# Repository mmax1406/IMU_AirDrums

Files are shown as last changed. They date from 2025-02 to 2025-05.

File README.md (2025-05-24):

# IMU_AirDrums

## Introduction
Using two BNO055 IMUs and an Arduino Uno to create air drums.
Each IMU provides absolute orientation data, which is sent to a Python script for processing.
After an initial calibration step, the 3D space is divided into five distinct zones: three lower (downward) strike zones and two upper strike zones.
When a movement is detected within one of these zones, it is interpreted as a drum hit.

## Setup
Each drum stick has a BN055 IMU 
<p float="left">
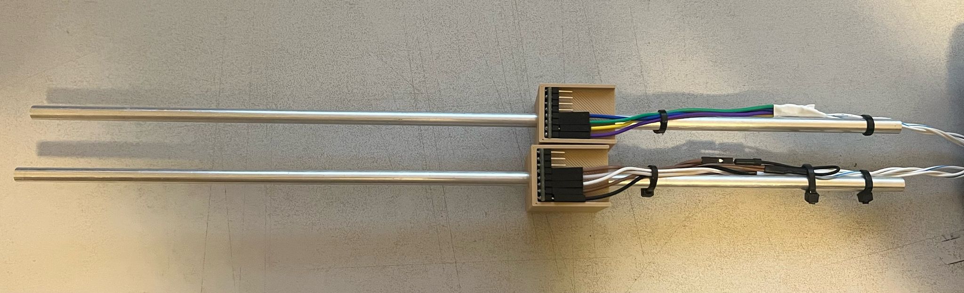
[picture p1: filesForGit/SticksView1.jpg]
  
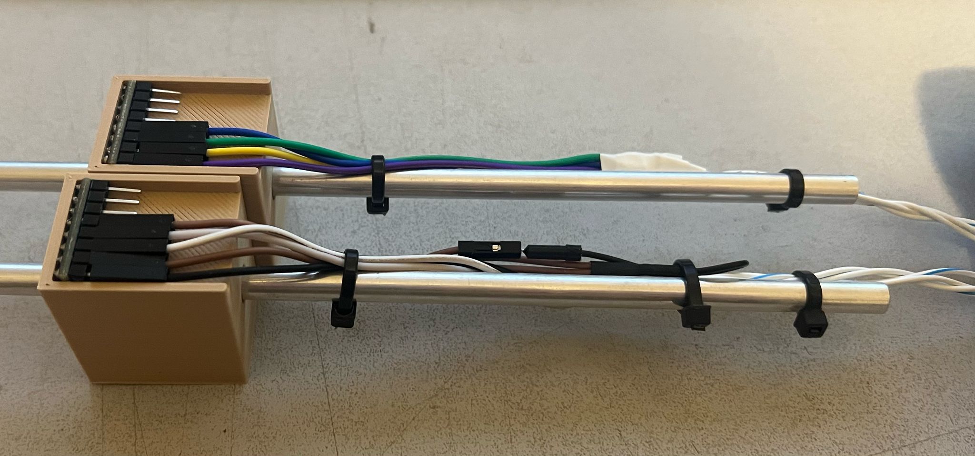
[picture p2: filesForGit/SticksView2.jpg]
   
</p>
note that the IMU allows 2 addresses 0x28 and 0x29 by shortning a pin so thats how they can sit on the same protocol.

And this is the Uno: 
<p float="left">
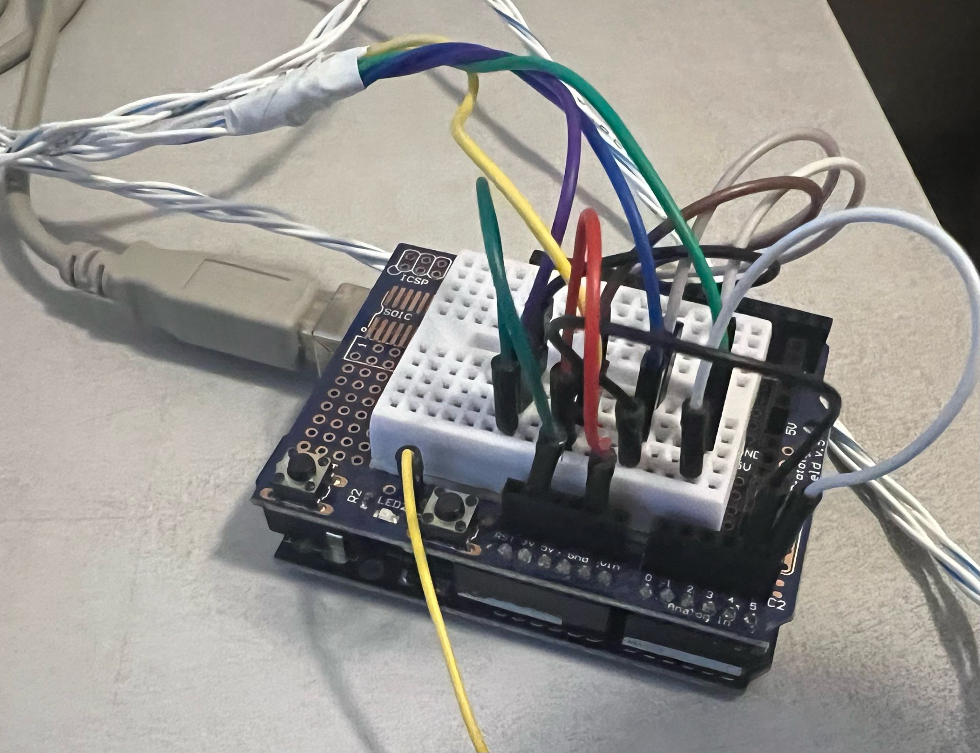
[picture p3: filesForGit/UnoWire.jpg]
  
</p>
Does it help? probably not ... but theres nothing special I2C on both sensors and electricty to them.

Finally on the PC side i wanted real drums so ive used an emulator called cakewalk with a drums plugin.
To connect to cakewalk ive used loopMIDI and sent the MIDI signal via python (this is the delay i can play with). 
<p float="left">
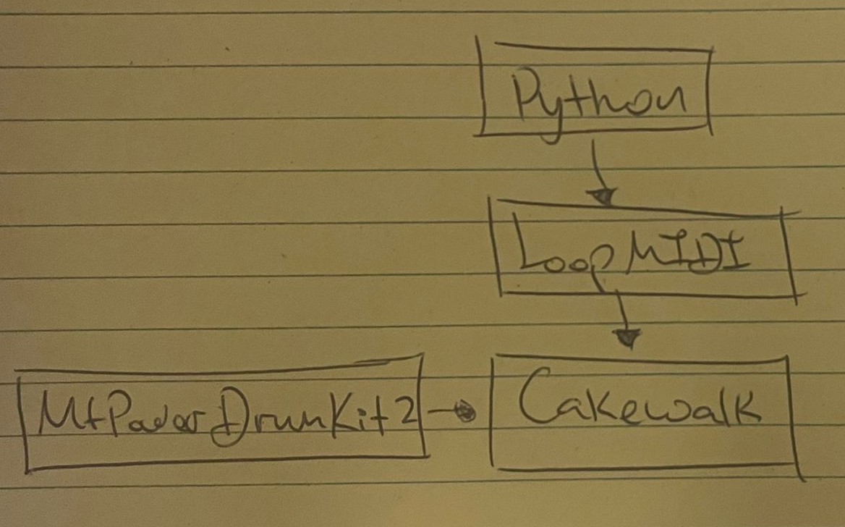
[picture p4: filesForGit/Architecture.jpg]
  
</p>

## To Do
- Hit Volume control using the accleration value.
- Work more on the delay reduction.

## Demonstration video
A small video of the system working

https://github.com/user-attachments/assets/ffe69c20-fb8f-49c2-923d-1a3709275ff4

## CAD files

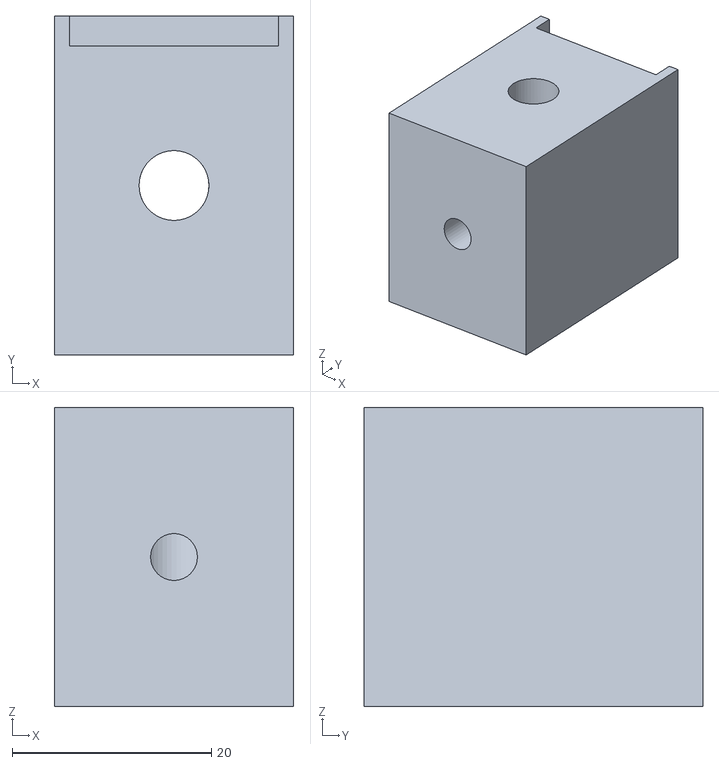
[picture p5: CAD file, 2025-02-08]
CAD/drumHandles v7.stl
24.0 x 34.0 x 30.0

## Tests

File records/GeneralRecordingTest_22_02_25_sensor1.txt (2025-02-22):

0,0.5224,0.4592,-0.5531,0.4586,3.0,-0.499215506284969,-0.2594394763192156,-1.659806445272789,-0.0023217320693640353,1740234139.310265
0,0.5224,0.4592,-0.5531,0.4586,3.0,-0.499215506284969,-0.2594394763192156,-1.6642553573984564,0.004448912125667448,1740234139.3344746
0,0.5224,0.4592,-0.5531,0.4586,3.0,-0.499215506284969,-0.2594394763192156,-1.6642553573984564,0.0,1740234139.3588767
0,0.5225,0.4592,-0.553,0.4586,3.0,-0.4995609359708624,-0.24676949321326447,-1.6515853742924962,-0.012669983105960236,1740234139.387862
0,0.5225,0.4592,-0.5531,0.4586,3.0,-0.5046526232843576,-0.2592316775084669,-1.676717541693674,0.02513216740117774,1740234139.4075923
0,0.5226,0.4591,-0.5532,0.4584,3.0,-0.533701835068257,-0.2615066053240014,-1.6665302852139872,-0.010187256479686768,1740234139.4366567
0,0.5228,0.4588,-0.5534,0.4581,3.0,-0.5917431239445818,-0.2555477528758274,-1.6582965049502956,-0.008233780263691592,1740234139.4583752
0,0.523,0.4586,-0.5536,0.4579,3.0,-0.6374510584867608,-0.2597687647429723,-1.6684763692656075,0.010179864315311926,1740234139.486153
0,0.5235,0.4583,-0.5537,0.4575,3.0,-0.7128977820971727,-0.24094031165444108,-1.6454269043099252,-0.023049464955682275,1740234139.5072882
0,0.5239,0.4581,-0.5538,0.4572,3.0,-0.7705657453064418,-0.23248306461948687,-1.6557981103635173,0.010371206053592097,1740234139.5351746
0,0.5239,0.4583,-0.5538,0.457,3.0,-0.7707013379435921,-0.2534949847946564,-1.6852672775736275,0.02946916721011017,1740234139.5597103
0,0.524,0.4584,-0.5536,0.4568,3.0,-0.7722356570513398,-0.23902117661725697,-1.649781549221064,-0.035485728352563584,1740234139.5846465
0,0.5242,0.4591,-0.5533,0.4563,3.0,-0.7559286220816546,-0.2744641329827857,-1.6996983137639876,0.04991676454292371,1740234139.6086006
0,0.524,0.4597,-0.5533,0.4561,3.0,-0.7207624732871238,-0.3373498162771398,-1.7271410406928194,0.027442726928831762,1740234139.6366847
0,0.5232,0.4609,-0.5532,0.4559,3.0,-0.6113215780771384,-0.45138435412221156,-1.778289895243525,0.051148854550705725,1740234139.6579187
0,0.5226,0.4617,-0.553,0.4561,3.0,-0.5072416529193333,-0.5104866750964732,-1.7233576783727096,-0.05493221687081551,1740234139.6879406
0,0.5212,0.4626,-0.5527,0.457,3.0,-0.30489913617370235,-0.5681595295005764,-1.7219282118025583,-0.0014294665701513054,1740234139.7068443
0,0.5197,0.4643,-0.5522,0.4576,3.0,-0.05672650505499632,-0.685489678650697,-1.7815855065485722,0.05965729474601389,1740234139.7369335
0,0.5175,0.4685,-0.5505,0.4579,3.0,0.42400975010556863,-0.9197436026850312,-1.8985092814327902,0.11692377488421801,1740234139.7600203
0,0.5162,0.471,-0.5494,0.458,3.0,0.7089370327789197,-1.0507065830338433,-1.7952183377472766,-0.10329094368551361,1740234139.7851458
0,0.5151,0.4725,-0.5481,0.4592,3.0,1.0012391636343807,-1.0495160161583783,-1.663064790522994,-0.13215354722428252,1740234139.8094158
0,0.515,0.4725,-0.5472,0.4604,3.0,1.1276243922799551,-0.9363763825241449,-1.5511157237642386,-0.11194906675875549,1740234139.83476
0,0.5148,0.4735,-0.5458,0.4614,3.0,1.3330308274845493,-0.8690072643486246,-1.5968862392229313,0.04577051545869271,1740234139.859683
0,0.5148,0.475,-0.5444,0.4614,3.0,1.4956394783668543,-0.8574049024610133,-1.6526529955108504,0.05576675628791916,1740234139.8875551
0,0.5141,0.4777,-0.5421,0.4622,3.0,1.8649696051639069,-0.8655749014226615,-1.6724253563600953,0.01977236084924483,1740234139.9084153
0,0.5125,0.4794,-0.5406,0.4639,3.0,2.2381942208633063,-0.8660936079718908,-1.6647740639476973,-0.007651292412397925,1740234139.936355
0,0.5093,0.4821,-0.538,0.4677,3.0,2.9466207696674473,-0.8420358671503152,-1.6401976165768724,-0.024576447370824983,1740234139.960444
0,0.5059,0.4832,-0.5357,0.4728,3.0,3.634703000009324,-0.6807353036776931,-1.5029547939258476,-0.13724282265102472,1740234139.9853165
0,0.4949,0.4847,-0.5342,0.4846,3.0,5.1375310599964905,-0.6628585268201732,-1.6463785805409485,0.1434237866151009,1740234140.010263
0,0.4868,0.4897,-0.5317,0.4903,3.0,6.371908646569352,-0.9165109226741492,-1.9179077532524293,0.2715291727114808,1740234140.0381656
0,0.4758,0.5004,-0.5271,0.4954,3.0,8.188974999935851,-1.572768394800704,-2.3205128295250175,0.4026050762725881,1740234140.0605896
0,0.4736,0.5043,-0.5275,0.4931,3.0,8.388872435348901,-2.0711036130591367,-2.1625905756568966,-0.15792225386812087,1740234140.0875502
0,0.4794,0.5134,-0.529,0.4763,3.0,7.478108755768744,-3.31707087585977,-2.910222620199093,0.7476320445421965,1740234140.1119683
0,0.4812,0.5167,-0.5315,0.4679,3.0,6.909572378509722,-4.014291974105191,-2.361476455643877,-0.5487461645552161,1740234140.1380346
0,0.4796,0.5173,-0.5344,0.4656,3.0,6.741255096479051,-4.44169858462314,-2.091661967916399,-0.2698144877274782,1740234140.1626542
0,0.4761,0.5131,-0.5374,0.4703,3.0,6.845099477211704,-4.313913518774569,-1.5364702915499002,-0.5551916763664986,1740234140.1873271
0,0.4726,0.5006,-0.541,0.483,3.0,6.923701430782472,-3.3020647798936125,-0.6524066185175048,-0.8840636730323954,1740234140.2105656
0,0.4681,0.4833,-0.5461,0.4991,3.0,6.866043682713752,-1.9826006592917622,-0.3447912367966217,-0.3076153817208831,1740234140.2360384
0,0.4657,0.4641,-0.5491,0.516,3.0,6.659024329712963,-0.2726030331818663,0.04574226871144749,-0.3905335055080692,1740234140.2599359
0,0.4854,0.4581,-0.5306,0.5225,3.0,6.43549880305045,2.650700635567887,1.2590483113512803,-1.2133060426398328,1740234140.288032
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

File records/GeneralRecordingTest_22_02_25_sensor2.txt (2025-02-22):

0,0.5986,0.3401,-0.636,0.3486,3.0,-0.536418361511835,0.06417728716959914,-1.659806445272789,-0.0023217320693640353,1740234139.310265
0,0.5986,0.34,-0.636,0.3485,3.0,-0.5505724291468539,0.07164669352081887,-1.6642553573984564,0.004448912125667448,1740234139.3344746
0,0.5986,0.34,-0.636,0.3486,3.0,-0.5434243245573498,0.07181386055944472,-1.6642553573984564,0.0,1740234139.3588767
0,0.5986,0.34,-0.636,0.3486,3.0,-0.5434243245573498,0.07181386055944472,-1.6515853742924962,-0.012669983105960236,1740234139.387862
0,0.5986,0.34,-0.636,0.3486,3.0,-0.5434243245573498,0.07181386055944472,-1.676717541693674,0.02513216740117774,1740234139.4075923
0,0.5986,0.34,-0.636,0.3486,3.0,-0.5434243245573498,0.07181386055944472,-1.6665302852139872,-0.010187256479686768,1740234139.4366567
0,0.5987,0.3398,-0.6361,0.3485,3.0,-0.5724923428326747,0.07291631738286242,-1.6582965049502956,-0.008233780263691592,1740234139.4583752
0,0.5988,0.3397,-0.6362,0.3484,3.0,-0.594551077794506,0.06638046631670136,-1.6684763692656075,0.010179864315311926,1740234139.486153
0,0.5989,0.3396,-0.6361,0.3483,3.0,-0.6091248279409172,0.08841482997519279,-1.6454269043099252,-0.023049464955682275,1740234139.5072882
0,0.5991,0.3395,-0.636,0.3482,3.0,-0.6278540534810304,0.11073360938473797,-1.6557981103635173,0.010371206053592097,1740234139.5351746
0,0.5991,0.3397,-0.636,0.348,3.0,-0.6281335294766563,0.09514583340956051,-1.6852672775736275,0.02946916721011017,1740234139.5597103
0,0.5992,0.3399,-0.636,0.3478,3.0,-0.632572844208596,0.07983526427142351,-1.649781549221064,-0.035485728352563584,1740234139.5846465
0,0.5992,0.3406,-0.6358,0.3475,3.0,-0.597505310296981,0.05440972325959592,-1.6996983137639876,0.04991676454292371,1740234139.6086006
0,0.5989,0.341,-0.6358,0.3474,3.0,-0.5642079556466797,0.022760094897506633,-1.7271410406928194,0.027442726928831762,1740234139.6366847
0,0.5981,0.342,-0.6361,0.3473,3.0,-0.47945597020788,-0.09925658931766179,-1.778289895243525,0.051148854550705725,1740234139.6579187
0,0.5975,0.3428,-0.6362,0.3475,3.0,-0.38803490867712753,-0.1764365966308219,-1.7233576783727096,-0.05493221687081551,1740234139.6879406
0,0.596,0.3442,-0.6364,0.3483,3.0,-0.17795708364195661,-0.3160076453251577,-1.7219282118025583,-0.0014294665701513054,1740234139.7068443
0,0.595,0.3461,-0.636,0.3489,3.0,0.054287828719679965,-0.40799688449504856,-1.7815855065485722,0.05965729474601389,1740234139.7369335
0,0.5933,0.3496,-0.6353,0.3497,3.0,0.45259039747031693,-0.5849997371463758,-1.8985092814327902,0.11692377488421801,1740234139.7600203
0,0.5924,0.3516,-0.6347,0.3502,3.0,0.6877092756929528,-0.6587203241599013,-1.7952183377472766,-0.10329094368551361,1740234139.7851458
0,0.5919,0.3526,-0.6334,0.3525,3.0,0.9924637186229575,-0.550121514579871,-1.663064790522994,-0.13215354722428252,1740234139.8094158
0,0.592,0.3526,-0.6323,0.3541,3.0,1.1447371561593798,-0.3908197321640614,-1.5511157237642386,-0.11194906675875549,1740234139.83476
0,0.5922,0.3535,-0.631,0.3553,3.0,1.3340839904083737,-0.27509181845826447,-1.5968862392229313,0.04577051545869271,1740234139.859683
0,0.5923,0.3548,-0.6301,0.3553,3.0,1.454532125171852,-0.25078507382593784,-1.6526529955108504,0.05576675628791916,1740234139.8875551
0,0.5924,0.3566,-0.6288,0.3557,3.0,1.6535812833377292,-0.20981442950903784,-1.6724253563600953,0.01977236084924483,1740234139.9084153
0,0.5919,0.3572,-0.6284,0.3567,3.0,1.8030117335405293,-0.201134358722328,-1.6647740639476973,-0.007651292412397925,1740234139.936355
0,0.5912,0.3578,-0.6277,0.3583,3.0,2.0153334697853893,-0.1498440188756831,-1.6401976165768724,-0.024576447370824983,1740234139.960444
0,0.5919,0.3583,-0.6271,0.3578,3.0,2.0078870165853573,-0.10435799420756098,-1.5029547939258476,-0.13724282265102472,1740234139.9853165
0,0.5941,0.3561,-0.627,0.3568,3.0,1.695195962016868,0.09075202194975418,-1.6463785805409485,0.1434237866151009,1740234140.010263
0,0.5973,0.3549,-0.6249,0.356,3.0,1.5024209825907633,0.4894948514121893,-1.9179077532524293,0.2715291727114808,1740234140.0381656
0,0.6011,0.3551,-0.6215,0.3554,3.0,1.4488259722860448,0.9590973102981764,-2.3205128295250175,0.4026050762725881,1740234140.0605896
0,0.6025,0.3588,-0.6168,0.3574,3.0,1.976534707385099,1.3233523953803967,-2.1625905756568966,-0.15792225386812087,1740234140.0875502
0,0.6023,0.3697,-0.6108,0.3571,3.0,2.9620268678089303,1.2575757645582826,-2.910222620199093,0.7476320445421965,1740234140.1119683
0,0.5942,0.3845,-0.6068,0.3618,3.0,4.810363703936332,0.5363390036081626,-2.361476455643877,-0.5487461645552161,1740234140.1380346
0,0.5844,0.3906,-0.6104,0.3651,3.0,5.723567987989213,-0.508599163084483,-2.091661967916399,-0.2698144877274782,1740234140.1626542
0,0.5659,0.3948,-0.6241,0.3666,3.0,6.366199759338286,-2.8304870335072394,-1.5364702915499002,-0.5551916763664986,1740234140.1873271
0,0.5521,0.3927,-0.6359,0.3696,3.0,6.610739215202642,-4.353053205761199,-0.6524066185175048,-0.8840636730323954,1740234140.2105656
0,0.5297,0.3735,-0.6562,0.3865,3.0,6.877853392249449,-5.683487583265332,-0.3447912367966217,-0.3076153817208831,1740234140.2360384
0,0.5275,0.3682,-0.6581,0.3912,3.0,6.900851674933563,-5.518534403525138,0.04574226871144749,-0.3905335055080692,1740234140.2599359
0,0.5384,0.3763,-0.6492,0.3835,3.0,6.673499722769975,-4.8702228045120535,1.2590483113512803,-1.2133060426398328,1740234140.288032
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

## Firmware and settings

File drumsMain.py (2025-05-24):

import serial
import numpy as np
from drumsClass import IMUSensorData
import keyboard  # For keypress detection
import time
import rtmidi
import os

# Set up the serial connection
ser = serial.Serial('COM5', 115200, timeout=0.05)  # Use a short timeout for non-blocking behavior

# Constants
SAMPLES_FOR_CALIBRATION = 100
HIT_THRESHOLD = -8 # Threshold for pitch rate detection (adjust as needed)
last_save_time1 = 0 # For a time debounce mechanism
last_save_time2 = 0 # For a time debounce mechanism
debounceTime = 0.1 # Time delay one theres no hit detection
hystersisAngle = 40

# For data logging
NumOfSamplesRecord = 1000
countRecord = 0
MaDataSensor1 = []
MaDataSensor2 = []
printFlag = False
windowSize = 5
hit1 = 0
hit2 = 0

# Initialize sensor objects
sensor1 = IMUSensorData(SAMPLES_FOR_CALIBRATION, windowSize)
sensor2 = IMUSensorData(SAMPLES_FOR_CALIBRATION, windowSize)

# MIDI channel (0-15). Channel 10 is usually reserved for drums in General MIDI.
MIDI_CHANNEL = 9  # MIDI channels are 0-indexed, so 9 = Channel 10
# Initialize MIDI output
midiout = rtmidi.MidiOut()
available_ports = midiout.get_ports()
# Open the first available port
if available_ports:
    midiout.open_port(0)
else:
    midiout.open_virtual_port("MyVirtualOutput")

def save_data():
    """Handles saving the recorded data after user input."""
    folder = "records"
    os.makedirs(folder, exist_ok=True)  # Create the folder if it doesn't exist

    filename = input("Enter a filename (without extension): ")
    filepath1 = os.path.join(folder, f"{filename}_sensor1.txt")
    filepath2 = os.path.join(folder, f"{filename}_sensor2.txt")

    with open(filepath1, "w") as f:
        for data in MaDataSensor1:
            f.write(",".join(map(str, data)) + "\n")

    with open(filepath2, "w") as f:
        for data in MaDataSensor2:
            f.write(",".join(map(str, data)) + "\n")

    print(f"Data saved in {folder} as {filename}_sensor1.txt and {filename}_sensor2.txt")

def send_midi_notes(notes, velocity=127, duration=0.05):
    # Function to send MIDI note
    for note in notes:
        if note>0:
            # Send Note On message
            note_on = [0x90 + MIDI_CHANNEL, note, velocity]  # 0x90 = Note On
            midiout.send_message(note_on)

    # Wait for the duration of the note
    time.sleep(duration)

    for note in notes:
        if note>0:
            # Send Note Off message
            note_off = [0x80 + MIDI_CHANNEL, note, 0]  # 0x80 = Note Off
            midiout.send_message(note_off)

def is_within_hit_zone(sensor_heading, sensor_pitch):
    # Basic hystersis idea
    if sensor_pitch>55:
        hystersisAngle = 30
    else:
        hystersisAngle = 40
    # Check if the current sensor angles are within the hit zone of any drum hit location. (Maybe add HYSTERSIS HERE?)
    note = 0
    if sensor_pitch<hystersisAngle:
        if sensor_heading<-25:
            note = 41
        elif sensor_heading>-25 and sensor_heading<25:
            note = 38
        elif sensor_heading > 25:
            note = 42    
    else:
        if sensor_heading<0:
            note = 51
        elif sensor_heading>0:
            note = 49

    return note

try:
    print("Listening for drum hits (Press Ctrl+C to exit)...")
    prev_accZ1 = prev_accZ2 = 0.0  # Previous acceleration values for jerk calculation

    while True:
        # Read a line of data from the serial port
        line = ser.readline().decode('utf-8').strip()
        if line:
            values = line.split()
            if len(values) == 10:  # Ensure there are exactly 8 values
                data = list(map(float, values))
                if not all(value == 0 for value in data):  # Ensure all values are non-zero
                    w1, x1, y1, z1, Calib1 = map(float, values[:5])
                    w2, x2, y2, z2, Calib2 = map(float, values[5:])

                    # Flag according to sensor's dara sheet that check whether its ok
                    if Calib1 == 0:
                        print('Sensor 1 No good')
                    if Calib2 == 0:
                        print('Sensor 2 No good')

                    # Deccide if an air drum was hit
                    if Calib1>0:
                        sensor1.process_data(w1, x1, y1, z1)                    
                        # Check if a drum hit occurs for sensor 1
                        if (sensor1.accP <= HIT_THRESHOLD and (time.time()-last_save_time1)>debounceTime):
                            hit1 = is_within_hit_zone(sensor1.heading, sensor1.pitch)
                            last_save_time1 = time.time()
                        else:
                            hit1 = 0    
                    if Calib2>0:
                        sensor2.process_data(w2, x2, y2, z2)
                        # Chek for hitting
                        hit2 = is_within_hit_zone(sensor2.heading, sensor2.pitch)
                        # Check if a drum hit occurs for sensor 2 
                        if (sensor2.accP <= HIT_THRESHOLD and (time.time()-last_save_time2)>debounceTime):
                            hit2 = is_within_hit_zone(sensor2.heading, sensor2.pitch)
                            last_save_time2 = time.time()
                        else:
                            hit2 = 0

                    # If at least one drum was hit than send the MIDI signal
                    if hit1 != 0 or hit2 != 0:
                        send_midi_notes([hit1, hit2])

                    # Print the angles for fun
                    print(f"L: H: {sensor1.heading:.3f}, P: {sensor1.pitch:.3f}, "
                            f"R: H: {sensor2.heading:.3f}, P: {sensor2.pitch:.3f}") 

                    # Some keyboard options for user
                    if keyboard.is_pressed('c'): # Calibrate them drums upon keboard press (I think i have mistake in the Average calculator)
                        sensor1.calibration_counter = 0.0
                        sensor2.calibration_counter = 0.0
                        
                    if keyboard.is_pressed('r') or printFlag: # Calibrate them drums upon keboard press
                        if printFlag == False:
                            print('Recording start')
                        if countRecord<NumOfSamplesRecord:
                            MaDataSensor1.append((hit1, w1, x1, y1, z1, Calib1, sensor1.heading, sensor1.pitch, sensor1.omegaP, sensor1.accP, time.time()))
                            MaDataSensor2.append((hit2, w2, x2, y2, z2, Calib2, sensor2.heading, sensor2.pitch, sensor1.omegaP, sensor1.accP, time.time()))
                            printFlag = True
                        else:
                            print("Recording finished. Enter filename to save.")
                            save_data()
                            printFlag = False  # Stop recording
                            countRecord = 0  # Reset counter
                            MaDataSensor1.clear()  # Clear previous data
                            MaDataSensor2.clear()
                        countRecord += 1

except KeyboardInterrupt:
    print("\nExiting program.")
finally:
    ser.close()
    midiout.close_port()
    del midiout
    print("Serial port closed.")

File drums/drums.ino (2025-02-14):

#include <Wire.h>
#include <Adafruit_Sensor.h>
#include <Adafruit_BNO055.h>
#include <utility/imumaths.h>

/* Set the delay between fresh samples and init some vars*/
#define BNO055_SAMPLERATE_DELAY_MS (10)
#define LOOP_PERIOD_MS 25
uint8_t system1 = 0, gyro1 = 0, accel1 = 0, mag1 = 0;
uint8_t system2 = 0, gyro2 = 0, accel2 = 0, mag2 = 0;
bool initialized = false; // Track if we passed the grace period
unsigned long startTime, lastUpdateTime;

// Check I2C device address and correct line below (by default address is 0x29 or 0x28) id, address
Adafruit_BNO055 bno = Adafruit_BNO055(55, 0x29);
Adafruit_BNO055 bno2 = Adafruit_BNO055(55, 0x28);

// Function to try and reconnect in case of disconnection
void attemptReconnect() {
  Serial.print(-1);
  Serial.print(F(" "));
  Serial.print(-2);
  Serial.print(F(" "));
  Serial.print(-3);
  Serial.print(F(" "));
  Serial.print(-4);
  Serial.print(F(" "));
  Serial.println(-5);

  if (!bno.begin()) {
    delay(10);
    return;
  }

  bno.setExtCrystalUse(true);

  initialized = false;
  startTime = millis(); // Record the start time
}

void setup(void)
{
  Serial.begin(115200);
  /* Initialise the sensor */
  if (!bno.begin())
  {
    Serial.print("Sensor 1 no good!");
    while (1);
  }
  /* Initialise the sensor */
  if (!bno2.begin())
  {
    Serial.print("Sensor 2 no good!");
    while (1);
  }

  bno.setExtCrystalUse(true);
  bno2.setExtCrystalUse(true);

  delay(1000);
  startTime = millis();  // Record startup time
  lastUpdateTime = millis(); // Initialize loop timing
}

void loop(void)
{

  // Run at 40Hz (every 25ms)
  unsigned long currentTime = millis();

  if (currentTime - lastUpdateTime >= LOOP_PERIOD_MS) {
    lastUpdateTime = currentTime;

    // Mechanism for disconnections
    // Allow 3 seconds before checking for sensor failure
    if ((currentTime - startTime) > 3000) {
      initialized = true;  // After 3 seconds, enable error checking
    }  
    // Check if all values are zero for more than N consecutive samples (indicating a sensor issue)

    // Normal operation sensor1
    imu::Quaternion quat = bno.getQuat();
    bno.getCalibration(&system1, &gyro1, &accel1, &mag1);
    Serial.print(quat.w(), 4);
    Serial.print(F(" "));
    Serial.print(quat.x(), 4);
    Serial.print(F(" "));
    Serial.print(quat.y(), 4);
    Serial.print(F(" "));
    Serial.print(quat.z(), 4);
    Serial.print(F(" "));
    Serial.print(system1, DEC);
    Serial.print(F(" "));

    // Normal operation sensor2
    imu::Quaternion quat2 = bno2.getQuat();
    bno2.getCalibration(&system2, &gyro2, &accel2, &mag2);
    Serial.print(quat2.w(), 4);
    Serial.print(F(" "));
    Serial.print(quat2.x(), 4);
    Serial.print(F(" "));
    Serial.print(quat2.y(), 4);
    Serial.print(F(" "));
    Serial.print(quat2.z(), 4);
    Serial.print(F(" "));
    Serial.println(system2, DEC);

    delay(BNO055_SAMPLERATE_DELAY_MS);
  }
}

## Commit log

2025-01-18 Completed the full route to send midi to the drum machine, but the algo itself as of now is not good enough
    [hitTest.xlsx]
2025-01-25 Some progress in understanding i need to wait for the sensor calibration but want to try to change to esp32 and WiFi server
    [hitTest.xlsx]
2025-02-01 Back to zero
    The drums worked. i went to basics with an esp32 and a single drum, realized the data is only good when sensor is calibrated... my connections (physical) are not so good so i had to try and make a "r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
2025-02-08 Made a lot of progress: 2 working sticks and more drumming sounds. need to play around with the values to lower the delay.
    [drumHandles v7.stl]
2025-02-12 Added New idea on how to test the locations of the sticks(filter them) and the hitting is via acceleration now
2025-02-14 So i dont like the classfication method ( the signal smoothing adds delay which is no good), so ive colected data to try KNN. also fixed small calibration mistake + better recording
    [drumHandles v7.stl]
2025-02-22 Found a mistake in the hit detection + added an option to hit 2 drums simultaneously , need to add hystersis for better classfication
    [drumsMain.py]
